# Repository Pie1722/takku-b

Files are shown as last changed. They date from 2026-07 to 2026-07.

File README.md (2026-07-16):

# takku:b

github intro

<p align="justify">
Most DIY binary watches sacrifice battery life for simplicity. I wanted to build one that could run for months from a CR2032 while still remaining compact and stylish. Using an STM32L0 microcontroller and aggressive power optimization, this watch sleeps at under 10 µA and only wakes when needed.
</p>
<p align="justify">
This watch consumes very little amount of power and thus it can run forever on the CR2032 battery but of course due to its self discharge, it will last for around 8-10 years. Along with time it shows weekday, date, month, year and you can even set alarms!
</p>

---

## Features

  1. Time (HH:MM)
  2. Weekday and Date
  3. Month and Year
  4. Set Alarm A and B
  5. Long lasting battery life "**4+ years**"
  6. Field watch style strap "**22mm NATO**"

## Reading Time

reading time

<p align = "justify">
Reading the time in this watch is very easy. Just as the name suggests, it shows time in binary, more specifically it shows in (BCD) Binary Coded Decimal. BCD is a type of encoding in which each number is represented by fixed number of bits. So to show time we need 4 number in which two are for hours and then the other two are for minutes. Each binary digit has its own weight. The bottom digit represents 1 and the top most represents 8. So we need 16 LEDs to show the time (4 rows and 4 columns).
</p>
<p align = "justify">
So to read the time just add the digits in which the LED is turned on and ignore the one's which are off. See the above figure for better understanding.
</p>

---

## How To Use?

wach label

**Note**: See the above figures for the naming conventions.

**General**

  1. Press the button (A) to turn on the display and see the time.
  2. To view Weekday and Date press the button (A) again. First two columns shows the Weekday in which Monday is represented by 1 and Sunday as 7 and the last two columns shows Date.
  3. To view Month and Year press the button (A) again. First two columns shows the Month and last two columns shows the year.
  4. This watch goes on in this cyclic way with each button press. First it shows Time -> Weekday & Date -> Month & Year. Time is represented with a beep to avoid confusion.
  5. The display remains on for 5 seconds. To change the display timeout see the Step 5.

**Setting Mode**

  1. To enter setting mode press the button (A) once to turn on the watch and got to the specific screen then keep pressing button (A) until you hear a beep which indicated you are in setting mode.
  2. To set the time press the button (A) and and enter the time screen and then keep pressing the button (A) until you hear a beep.
  3. Once inside setting mode, press button (B) to increment the numbers.
  4. To change the current field inside the setting mode then press button (C) once. Example - After setting the Hour then press button (C) and set the minutes. If the button (C) is pressed again it will go again to the hour setting mode.
  5. To exit the setting mode, keep pressing the button (A) until you hear a beep.
  6. For setting the other parameter of the watch go to that specific screen and follow the above instruction.

**Setting Alarm**

  1. To view the current alarm, press button (C) after turning the watch on.
  2. To turn on the alarm press the button (B) and same to turn it off. The alarm turned on will be indicated by a red led.
  3. To edit the alarm, press button (A) for one second until you hear the beep, to enter alarm editing mode.
  4. Then use button (B) to increment the value.
  5. To change the field between hour and minute, press button (C).
  6. To exit the alarm edit mode press the button (A) for one second till you hear the beep.
  7. Then either turn on or turn off the alarm by pressing the button (B).
  8. To stop the alarm after it is triggered at the set time, press button (A).
     
  **Note**: The alarm time is stored even if the battery is removed. But it wont be enabled, to turn on the alarm, enter the alarm mode and press the button (B) to turn it on.

**Flow Of Screen**

    Normal Mode -> Screen Time -> Screen Weekday_Date -> Screen Month_Year

---

# Hardware

## PCB Design

The PCB is fully open-sourced and is designed in EasyEDA standard edition. The PCB size is 36mm * 36mm. You can download the gerber files for PCB manufacturing from [/Gerber](Gerber/)

Schematic_Binary-Watch_2026-06-24



3d

## CAD Design

The watch enclosure was designed considering the PCB dimensions. We used a standard 22mm spacing for the watch strap. Designed considered Using a NATO watch strap. The enclosure was designed with tolerance to avoid manufacturing inaccuracies. The design includes a total of 8 holes. 4 holes in front for mounting the glass and four in back to mount the back panel. Inserts are used has it's difficult to print the threads accurately. The back panel is designed big enough so that the battery can be replaced easily. The edges of the enclosure were rounded to avoid sharp edges. And overall design of all components was kept minimalist so it would be better for 3D printing
FDKBVOYMR0Y8SGP-ezgif com-video-to-gif-converter

cad

---

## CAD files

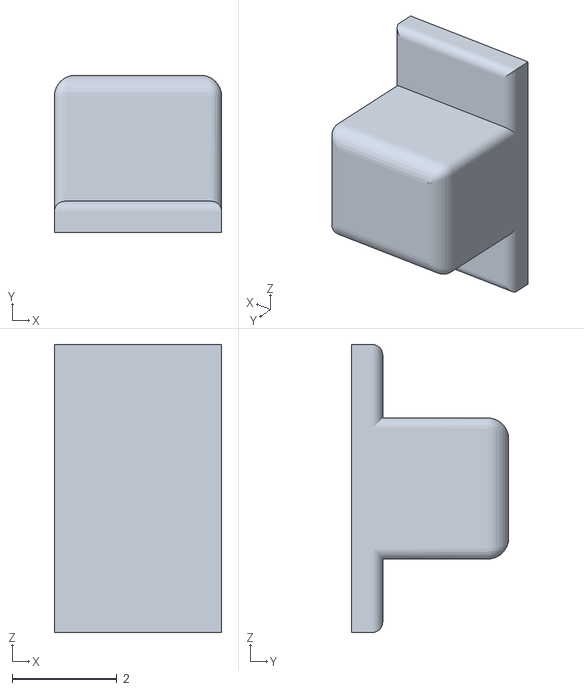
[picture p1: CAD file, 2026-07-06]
3D CAD/Button.stl
3.19 x 3.00 x 5.49

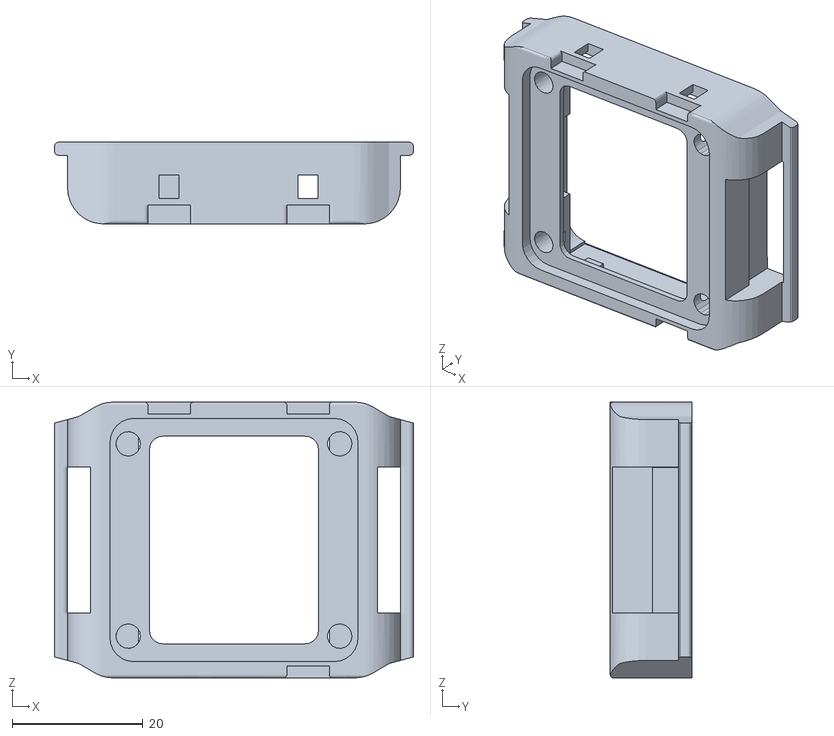
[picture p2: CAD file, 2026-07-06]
3D CAD/Body.stl
55.0 x 12.5 x 42.3

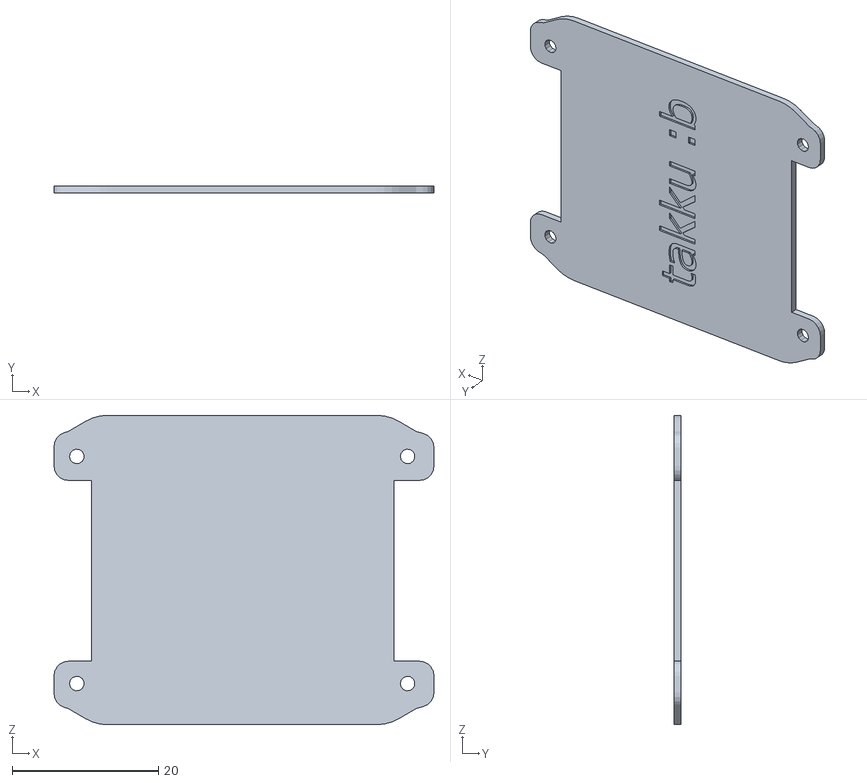
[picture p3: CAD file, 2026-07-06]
3D CAD/Back Panel.stl
51.9 x 1.00 x 42.3

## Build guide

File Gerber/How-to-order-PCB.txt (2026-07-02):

How to Order PCB

Please refer to:
https://docs.easyeda.com/en/PCB/Order-PCB

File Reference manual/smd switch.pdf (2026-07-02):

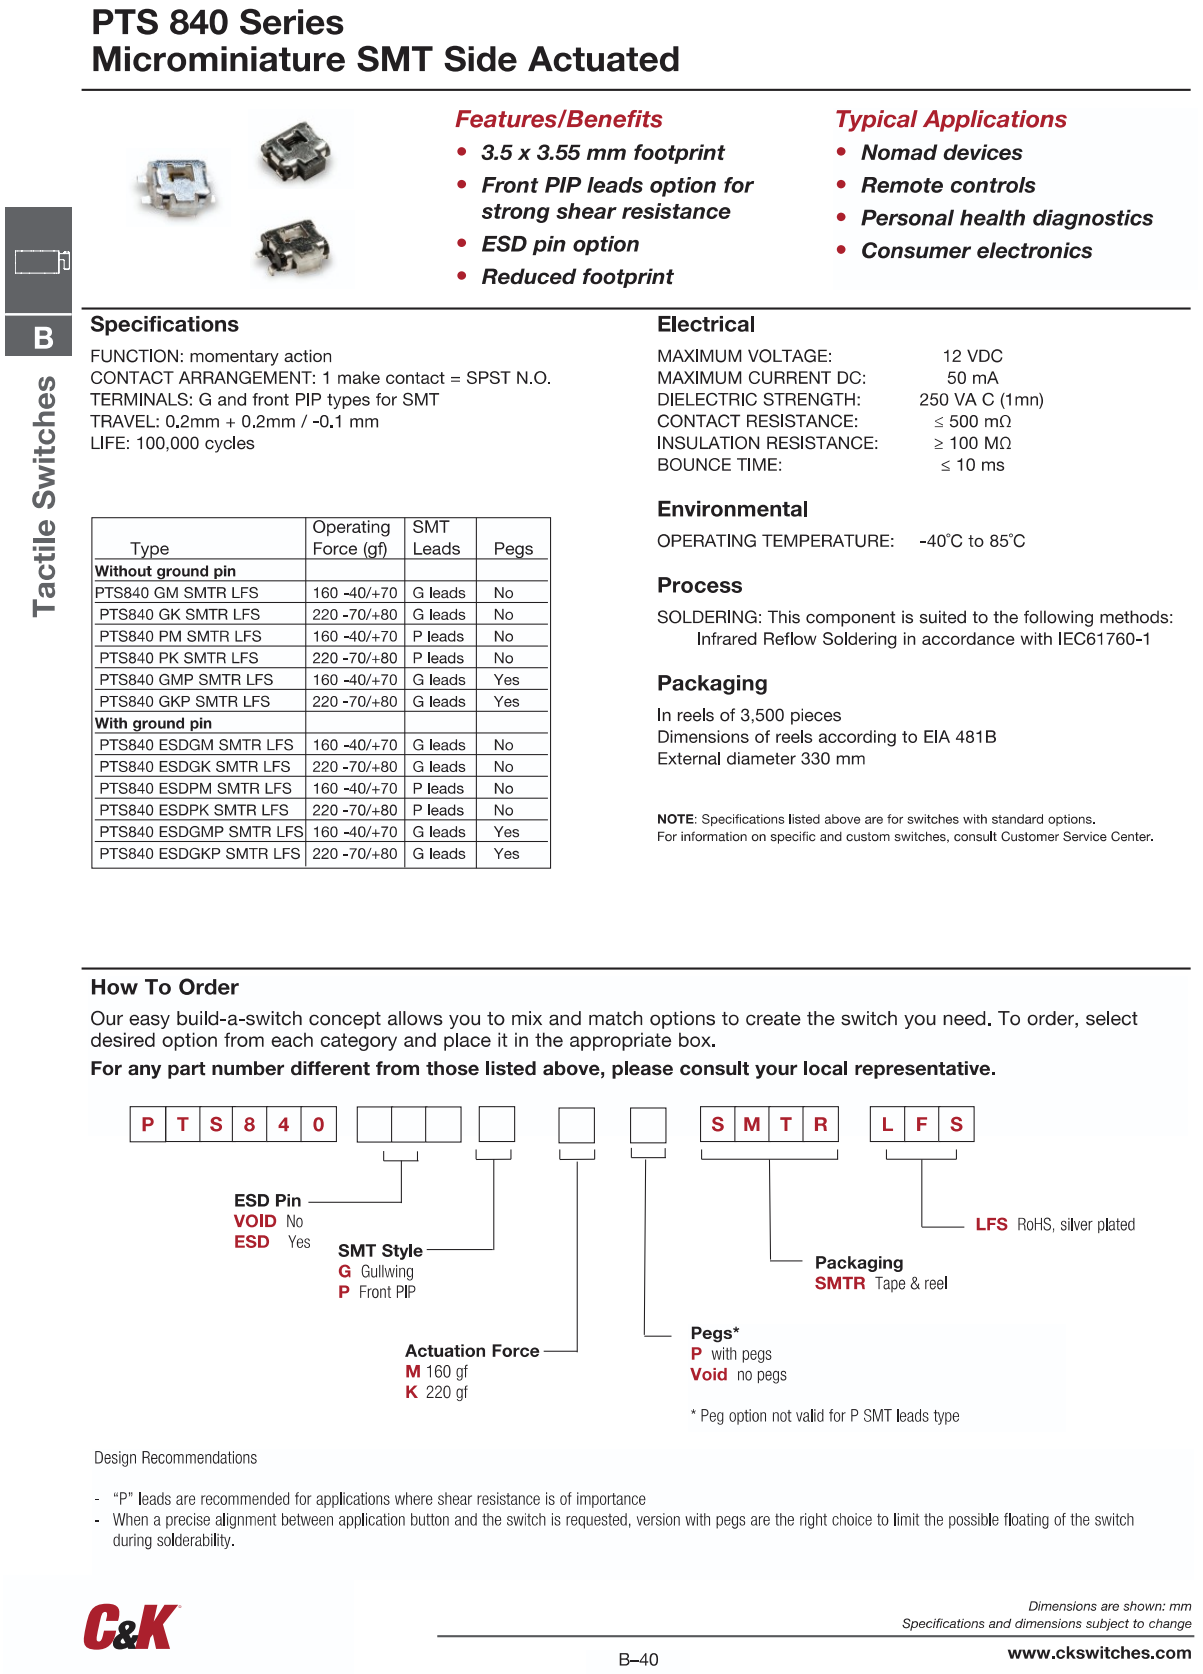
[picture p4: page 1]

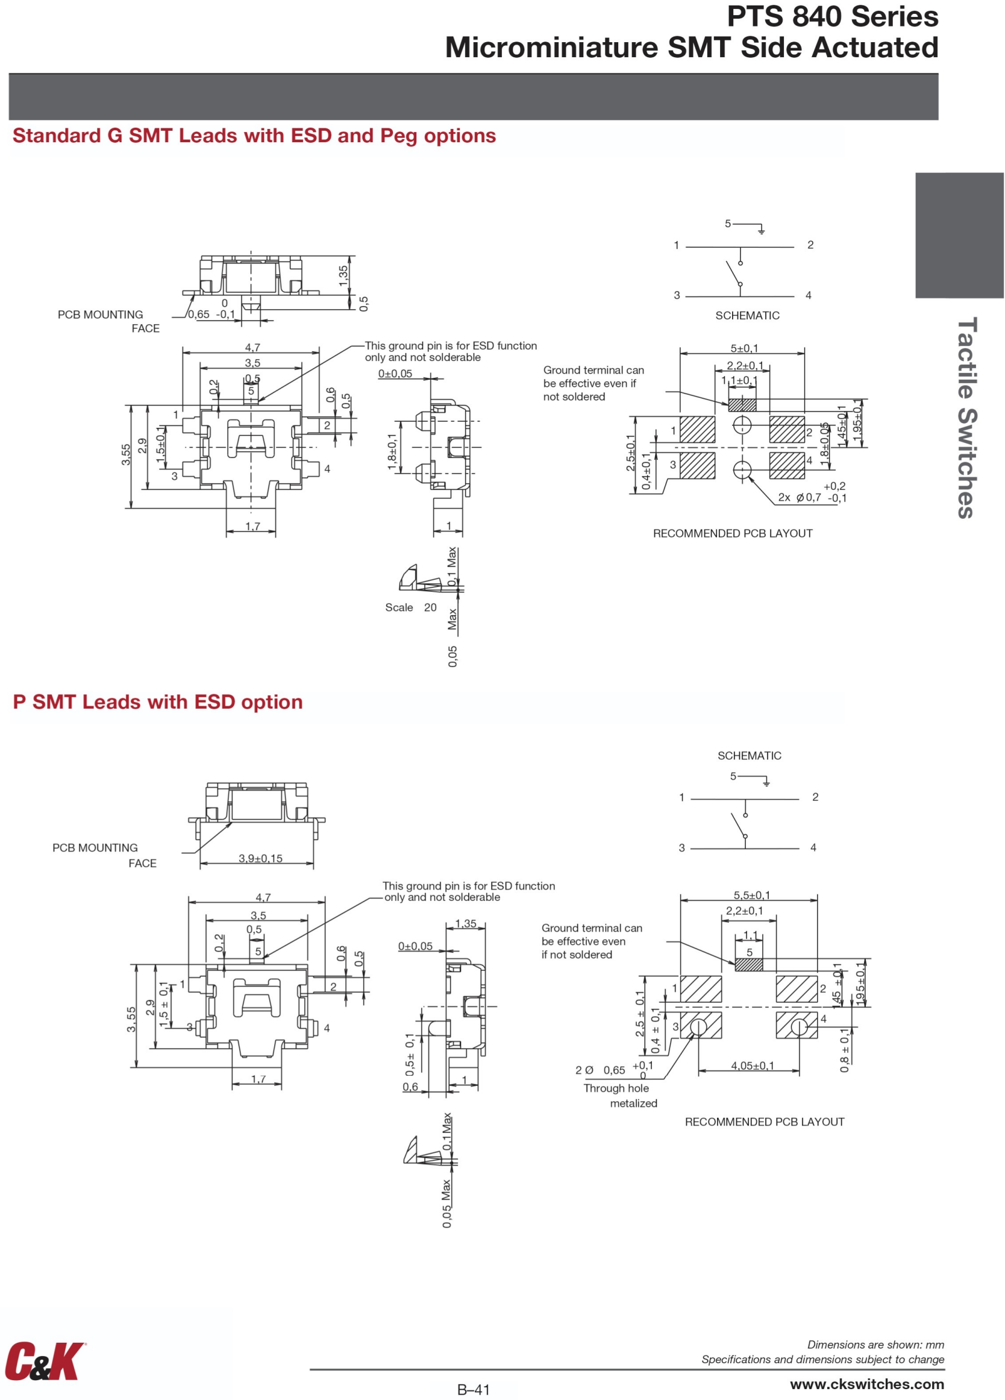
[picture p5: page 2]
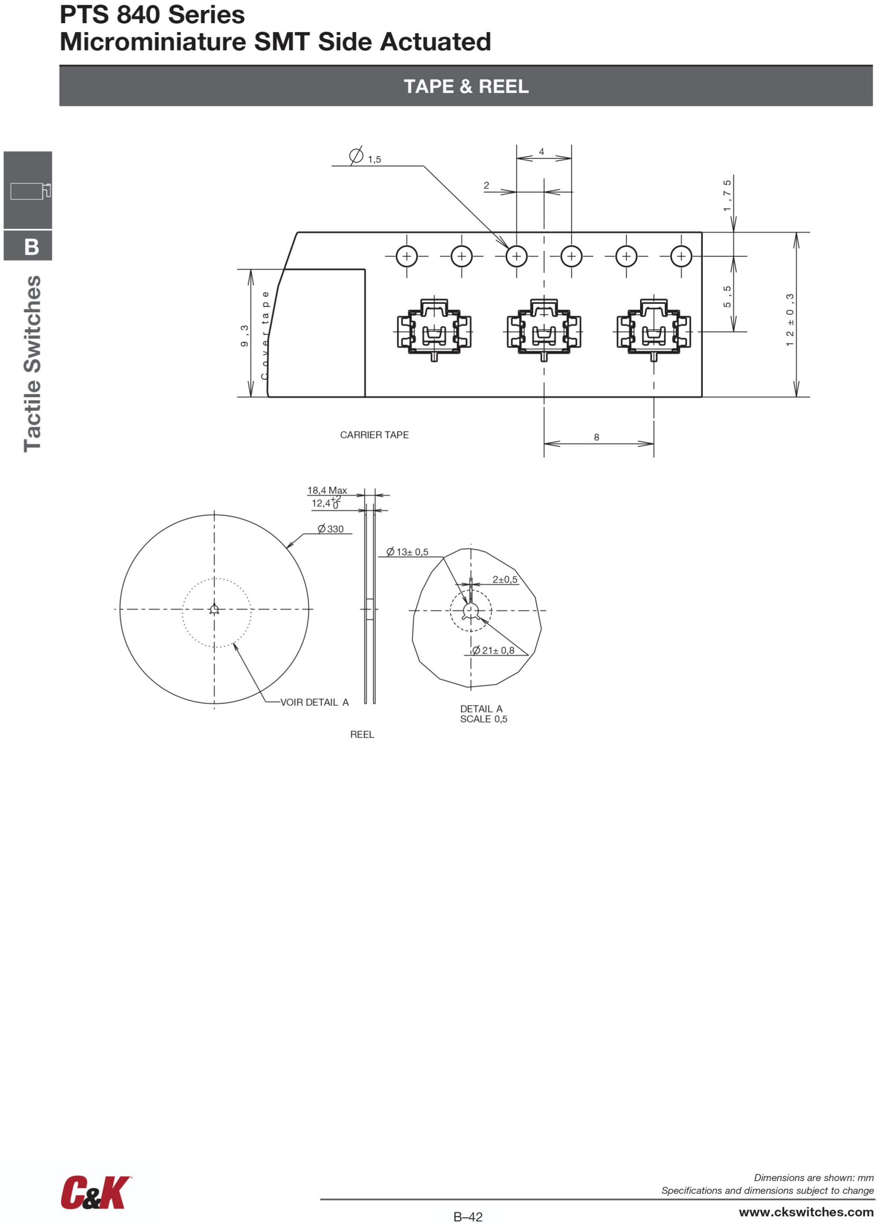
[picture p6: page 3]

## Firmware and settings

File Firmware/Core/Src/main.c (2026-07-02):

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
/* Includes ------------------------------------------------------------------*/
#include "main.h"

/* USER CODE BEGIN PTD */
typedef enum
{
    SCREEN_TIME,
    SCREEN_DATE,
    SCREEN_YEAR,
	SCREEN_ALARM
} DisplayScreen_t;

typedef enum
{
    MODE_NORMAL,
    MODE_SET_HOUR,
    MODE_SET_MINUTE,
    MODE_SET_WEEKDAY,
    MODE_SET_DATE,
    MODE_SET_MONTH,
    MODE_SET_YEAR,
	MODE_SET_ALARM_HOUR,
	MODE_SET_ALARM_MINUTE
} WatchMode_t;
/* USER CODE END PTD */

/* USER CODE BEGIN PD */
uint8_t matrix[4][4]; // 2D array for display

uint8_t hour_tens;
uint8_t hour_ones;
uint8_t min_tens;
uint8_t min_ones;

uint8_t day_tens;
uint8_t day_ones;
uint8_t date_tens;
uint8_t date_ones;

uint8_t year_tens;
uint8_t year_ones;
uint8_t month_tens;
uint8_t month_ones;

uint8_t editHour;
uint8_t editMinute;
uint8_t editWeekday;
uint8_t editDate;
uint8_t editMonth;
uint8_t editYear;

uint8_t alarmHour = 0;
uint8_t alarmMinute = 0;
uint8_t editAlarmHour;
uint8_t editAlarmMinute;
uint8_t alarmEnabled = 0;
uint8_t alarmActive = 0;        // Alarm currently sounding
uint32_t alarmStartTime = 0;    // When the alarm started
uint32_t alarmTimer = 0;        // Timing between beeps
uint8_t beepCount = 0;          // 0..3 beeps in the current burst
uint8_t buzzerOn = 0;           // 0 = OFF, 1 = ON

uint32_t displayTimeout = 0;
uint8_t displayEnabled = 0;

uint32_t buttonPressTime[3] = {0};
uint8_t buttonPressed[3] = {0};
uint32_t lastButtonInterrupt[3] = {0};   // debounce timer

uint8_t settingMode = 0;
/* USER CODE END PD */

RTC_HandleTypeDef hrtc;

TIM_HandleTypeDef htim2;
TIM_HandleTypeDef htim21;

void SystemClock_Config(void);
static void MX_GPIO_Init(void);
static void MX_RTC_Init(void);
static void MX_TIM2_Init(void);
static void MX_TIM21_Init(void);
/* USER CODE BEGIN 0 */

/*
 * Store the pattern in memory matrix
 * The digit and the column where to print is sent.
 * Then the row is selected by the AND operation and check if the output is true or false (1 or 0)
 * 		digit = 6 = 0110
 * 		0110 * 1000 = 0 so the 8th bit row will turn off
 * 		0110 * 0100 = 1 so the 4th bit row will turn on
 * 		0110 * 0010 = 1 so the 2nd bit row will turn on
 * 		0110 * 0001 = 0 so the 1st bit row will turn off
 */
void SetColumnMem(uint8_t col, uint8_t digit)
{
    matrix[0][col] = (digit & 0x08) ? 1 : 0; // 8
    matrix[1][col] = (digit & 0x04) ? 1 : 0; // 4
    matrix[2][col] = (digit & 0x02) ? 1 : 0; // 2
    matrix[3][col] = (digit & 0x01) ? 1 : 0; // 1
}

// Turn off LEDs before the next pattern
void DisableAllColumns(void)
{
    HAL_GPIO_WritePin(GPIOA, COL_1_Pin, GPIO_PIN_SET);
    HAL_GPIO_WritePin(GPIOA, COL_2_Pin, GPIO_PIN_SET);
    HAL_GPIO_WritePin(GPIOA, COL_3_Pin, GPIO_PIN_SET);
    HAL_GPIO_WritePin(GPIOA, COL_4_Pin, GPIO_PIN_SET);
}

//------ Convert the patter stored in memory to GPIO ---------

/*
 * Check each matrix to see which row is to be set or reset.
 * if matrix[0][1] is set then set the row 4 pin
 */
void SetRows(uint8_t col)
{
    HAL_GPIO_WritePin(GPIOB, ROW_1_Pin,
        matrix[0][col] ? GPIO_PIN_SET : GPIO_PIN_RESET);

    HAL_GPIO_WritePin(GPIOB, ROW_2_Pin,
        matrix[1][col] ? GPIO_PIN_SET : GPIO_PIN_RESET);

    HAL_GPIO_WritePin(GPIOB, ROW_3_Pin,
        matrix[2][col] ? GPIO_PIN_SET : GPIO_PIN_RESET);

    HAL_GPIO_WritePin(GPIOB, ROW_4_Pin,
        matrix[3][col] ? GPIO_PIN_SET : GPIO_PIN_RESET);
}

// Reset the column based on the user column entry
void SetColumn(uint8_t col)
{
    switch(col)
    {
        case 0:
            HAL_GPIO_WritePin(GPIOA, COL_1_Pin, GPIO_PIN_RESET);
            break;

        case 1:
            HAL_GPIO_WritePin(GPIOA, COL_2_Pin, GPIO_PIN_RESET);
            break;

        case 2:
            HAL_GPIO_WritePin(GPIOA, COL_3_Pin, GPIO_PIN_RESET);
            break;

        case 3:
            HAL_GPIO_WritePin(GPIOA, COL_4_Pin, GPIO_PIN_RESET);
            break;
    }
}

void getTime(void)
{
	RTC_TimeTypeDef sTime;
	RTC_DateTypeDef sDate;

    /* Get the RTC current Time */
	HAL_RTC_GetTime(&hrtc, &sTime, RTC_FORMAT_BIN);
	/* Get the RTC current Date */
    HAL_RTC_GetDate(&hrtc, &sDate, RTC_FORMAT_BIN);

    hour_tens = sTime.Hours / 10;
    hour_ones = sTime.Hours % 10;
    min_tens  = sTime.Minutes / 10;
    min_ones  = sTime.Minutes % 10;

    // HH : MM
    SetColumnMem(0, hour_tens);
    SetColumnMem(1, hour_ones);
    SetColumnMem(2, min_tens);
    SetColumnMem(3, min_ones);
}

void getDate(void)
{
	RTC_TimeTypeDef sTime;
	RTC_DateTypeDef sDate;

    /* Get the RTC current Time */
	HAL_RTC_GetTime(&hrtc, &sTime, RTC_FORMAT_BIN);
	/* Get the RTC current Date */
    HAL_RTC_GetDate(&hrtc, &sDate, RTC_FORMAT_BIN);

    day_tens = sDate.WeekDay / 10;
    day_ones = sDate.WeekDay % 10;
    date_tens  = sDate.Date / 10;
    date_ones  = sDate.Date % 10;

    // WD : DD
    SetColumnMem(0, day_tens);
    SetColumnMem(1, day_ones);
    SetColumnMem(2, date_tens);
    SetColumnMem(3, date_ones);
}

void getYear(void)
{
	RTC_TimeTypeDef sTime;
	RTC_DateTypeDef sDate;

    /* Get the RTC current Time */
	HAL_RTC_GetTime(&hrtc, &sTime, RTC_FORMAT_BIN);
	/* Get the RTC current Date */
    HAL_RTC_GetDate(&hrtc, &sDate, RTC_FORMAT_BIN);

    month_tens = sDate.Month / 10;
    month_ones = sDate.Month % 10;
    year_tens  = sDate.Year / 10;
    year_ones  = sDate.Year % 10;

    // MM : YY
    SetColumnMem(0, month_tens);
    SetColumnMem(1, month_ones);
    SetColumnMem(2, year_tens);
    SetColumnMem(3, year_ones);
}

/*
 * Initialize the enum with default screen and mode and change the enum to enter the different modes.
 * See the functions below for more info
 */
DisplayScreen_t currentScreen = SCREEN_YEAR;
WatchMode_t currentMode = MODE_NORMAL;

/*
 * Entering to setting mode based on the screens
 * So if the currentScreen is SCREEN_TIME
 * then it should go into MODE_SET_HOUR to change the hour.
*/
void EnterSettingMode(void)
{
    RTC_TimeTypeDef sTime;
    RTC_DateTypeDef sDate;

    HAL_RTC_GetTime(&hrtc, &sTime, RTC_FORMAT_BIN);
    HAL_RTC_GetDate(&hrtc, &sDate, RTC_FORMAT_BIN);

    editHour = sTime.Hours;
    editMinute = sTime.Minutes;

    editWeekday = sDate.WeekDay;
    editDate = sDate.Date;

    editMonth = sDate.Month;
    editYear = sDate.Year;

    switch(currentScreen) // Check the currentScreen typedef and enter the appropriate setting modes
    {
        case SCREEN_TIME:
            currentMode = MODE_SET_HOUR; // Change the Hours
            break;

        case SCREEN_DATE:
            currentMode = MODE_SET_WEEKDAY; // Change the Weekday
            break;

        case SCREEN_YEAR:
            currentMode = MODE_SET_MONTH; // Change the month
            break;

        case SCREEN_ALARM:

            editAlarmHour = alarmHour;
            editAlarmMinute = alarmMinute;
            currentMode = MODE_SET_ALARM_HOUR;
            break;
    }
}

/*
 * Once we are inside setting a particular mode then we need to change the mode
 * to set the other field.
 * So after setting the hour we need to set the minutes.
 */
void NextField(void)
{
    switch(currentMode) // Check the currentMode typedef and go into the next mode to change the num
    {
        case MODE_SET_HOUR: // is current mode is in setting hour
            currentMode = MODE_SET_MINUTE; // then enter setting minute once this function is called
            break;
        case MODE_SET_MINUTE:
            currentMode = MODE_SET_HOUR;
            break;

        case MODE_SET_WEEKDAY:
            currentMode = MODE_SET_DATE;
            break;
        case MODE_SET_DATE:
            currentMode = MODE_SET_WEEKDAY;
            break;

        case MODE_SET_MONTH:
            currentMode = MODE_SET_YEAR;
            break;
        case MODE_SET_YEAR:
            currentMode = MODE_SET_MONTH;
            break;

        case MODE_SET_ALARM_HOUR:
            currentMode = MODE_SET_ALARM_MINUTE;
            break;
        case MODE_SET_ALARM_MINUTE:
            currentMode = MODE_SET_ALARM_HOUR;
            break;

        default:
            currentMode = MODE_NORMAL;
            break;
    }
}

/*
 * This function is to increment the values in each and every mode based on the
 * current mode.
 *
 * SCREEN_TIME:
 * 			MODE_SET_HOUR
 * 			MODE_SET_MINUTE
 * SCREEN_DAY:
 * 			MODE_SET_WEEKDAY
 * 			MODE_SET_DAY
 * SCREEN_YEAR:
 * 			MODE_SET_MONTH
 * 			MODE_SET_YEAR
 *
 * All the changes to the time is done to temp variables.
 */

void IncrementCurrentField(void)
{
    switch(currentMode)
    {
        case MODE_SET_HOUR:

            editHour++;

            if(editHour > 23)
                editHour = 0;

            break;

        case MODE_SET_MINUTE:

            editMinute++;

            if(editMinute > 59)
                editMinute = 0;

            break;

        case MODE_SET_WEEKDAY:

            editWeekday++;

            if(editWeekday > 7)
                editWeekday = 1;

            break;

        case MODE_SET_DATE:

            editDate++;

            if(editDate > 31)
                editDate = 1;

            break;

        case MODE_SET_MONTH:

            editMonth++;

            if(editMonth > 12)
                editMonth = 1;

            break;

        case MODE_SET_YEAR:

            editYear++;

            if(editYear > 99)
                editYear = 0;

            break;

        case MODE_SET_ALARM_HOUR:

            editAlarmHour++;

            if(editAlarmHour > 23)
            {
                editAlarmHour = 0;
            }

            break;

        case MODE_SET_ALARM_MINUTE:

            editAlarmMinute++;

            if(editAlarmMinute > 59)
            {
                editAlarmMinute = 0;
            }

            break;

        default:
            break;
    }
}

void ShowSettingValue(void)
{
    switch(currentScreen)
    {
        case SCREEN_TIME:

            SetColumnMem(0, editHour / 10);
            SetColumnMem(1, editHour % 10);
            SetColumnMem(2, editMinute / 10);
            SetColumnMem(3, editMinute % 10);

            break;

        case SCREEN_DATE:

            SetColumnMem(0, editWeekday / 10);
            SetColumnMem(1, editWeekday % 10);
            SetColumnMem(2, editDate / 10);
            SetColumnMem(3, editDate % 10);

            break;

        case SCREEN_YEAR:

            SetColumnMem(0, editMonth / 10);
            SetColumnMem(1, editMonth % 10);
            SetColumnMem(2, editYear / 10);
            SetColumnMem(3, editYear % 10);

            break;

        case SCREEN_ALARM:

            SetColumnMem(0, editAlarmHour / 10);
            SetColumnMem(1, editAlarmHour % 10);
            SetColumnMem(2, editAlarmMinute / 10);
            SetColumnMem(3, editAlarmMinute % 10);

            break;
    }
}

void beep()
{

    HAL_TIM_PWM_Start(&htim21, TIM_CHANNEL_2);

    HAL_Delay(20);

    HAL_TIM_PWM_Stop(&htim21, TIM_CHANNEL_2);
}

void getAlarm(void)
{
    SetColumnMem(0, alarmHour / 10);
    SetColumnMem(1, alarmHour % 10);
    SetColumnMem(2, alarmMinute / 10);
    SetColumnMem(3, alarmMinute % 10);

    if(alarmEnabled)
    {
        matrix[0][0] = 1;
    }
    else
    {
        matrix[0][0] = 0;
    }
}
/* USER CODE END 0 */

/**
  * @brief  The application entry point.
  * @retval int
  */
int main(void)
{

  /* MCU Configuration--------------------------------------------------------*/

  /* Reset of all peripherals, Initializes the Flash interface and the Systick. */
  HAL_Init();

  /* Configure the system clock */
  SystemClock_Config();

  /* Initialize all configured peripherals */
  MX_GPIO_Init();
  MX_RTC_Init();
  MX_TIM2_Init();
  MX_TIM21_Init();
  /* USER CODE BEGIN 2 */
  HAL_TIM_Base_Start_IT(&htim2);
  __HAL_TIM_SET_COMPARE(&htim21, TIM_CHANNEL_2, 50);

  // read the alarm  from eeprom
  alarmHour = *(uint8_t *)0x08080000;
  alarmMinute = *(uint8_t *)0x08080001;
//beep();
//  __HAL_TIM_SET_COMPARE(&htim21, TIM_CHANNEL_2, 250);
//  HAL_TIM_PWM_Start(&htim21, TIM_CHANNEL_2);
  /* USER CODE END 2 */

  /* Infinite loop */
  /* USER CODE BEGIN WHILE */
  while (1)
  {
	  if(alarmActive && buttonPressed[0])
	  {
	      alarmActive = 0;
	      HAL_TIM_PWM_Stop(&htim21, TIM_CHANNEL_2);
	      buttonPressed[0] = 0;
	  }

	  if(alarmActive)
	  {
	      uint32_t now = HAL_GetTick();

	      // Stop after 20 seconds
	      if((now - alarmStartTime) >= 20000)
	      {
	          alarmActive = 0;
	          HAL_TIM_PWM_Stop(&htim21, TIM_CHANNEL_2);
	      }
	      else
	      {
	          if(buzzerOn)
	          {
	              // ON for 80ms
	              if((now - alarmTimer) >= 80)
	              {
	                  HAL_TIM_PWM_Stop(&htim21, TIM_CHANNEL_2);

	                  buzzerOn = 0;
	                  alarmTimer = now;

	                  beepCount++;
	              }
	          }
	          else
	          {
	              if(beepCount < 4)
	              {
	                  // OFF between beeps (80ms)
	                  if((now - alarmTimer) >= 80)
	                  {
	                      HAL_TIM_PWM_Start(&htim21, TIM_CHANNEL_2);

	                      buzzerOn = 1;
	                      alarmTimer = now;
	                  }
	              }
	              else
	              {
	                  // Pause after 4 beeps (250ms)
	                  if((now - alarmTimer) >= 500)
	                  {
	                      beepCount = 0;

	                      HAL_TIM_PWM_Start(&htim21, TIM_CHANNEL_2);

	                      buzzerOn = 1;
	                      alarmTimer = now;
	                  }
	              }
	          }
	      }
	  }

	  if(currentMode == MODE_NORMAL)
	  {
	      if(HAL_GPIO_ReadPin(GPIOB, GPIO_PIN_2) == GPIO_PIN_RESET)
	      {
	          uint32_t now = HAL_GetTick();

	          if(buttonPressed[2] == 0 &&
	             (now - lastButtonInterrupt[2]) > 100)
	          {
	              if(currentScreen != SCREEN_ALARM)
	              {
	                  currentScreen = SCREEN_ALARM;
	                  getAlarm();
	              }
	              else
	              {
	                  currentScreen = SCREEN_TIME;
	                  getTime();
	              }

	              displayEnabled = 1;
	              displayTimeout = HAL_GetTick();

	              beep();

	              buttonPressed[2] = 1;
	              lastButtonInterrupt[2] = now;
	          }
	      }
	      else
	      {
	          buttonPressed[2] = 0;
	      }
	  }

	  if(currentMode == MODE_NORMAL && currentScreen == SCREEN_ALARM)
	  {
	      if(HAL_GPIO_ReadPin(GPIOB, GPIO_PIN_1) == GPIO_PIN_RESET)
	      {
	          uint32_t now = HAL_GetTick();

	          if(buttonPressed[1] == 0 &&
	              (now - lastButtonInterrupt[1]) > 100)
	          {
	              alarmEnabled = !alarmEnabled;

	              if(alarmEnabled)
	              {
	                  RTC_AlarmTypeDef sAlarm = {0};

	                  sAlarm.AlarmTime.Hours = alarmHour;
	                  sAlarm.AlarmTime.Minutes = alarmMinute;
	                  sAlarm.AlarmTime.Seconds = 0;
	                  sAlarm.AlarmTime.SubSeconds = 0;
	                  sAlarm.AlarmTime.DayLightSaving = RTC_DAYLIGHTSAVING_NONE;
	                  sAlarm.AlarmTime.StoreOperation = RTC_STOREOPERATION_RESET;
	                  sAlarm.AlarmMask = RTC_ALARMMASK_DATEWEEKDAY;
	                  sAlarm.AlarmSubSecondMask = RTC_ALARMSUBSECONDMASK_ALL;
	                  sAlarm.AlarmDateWeekDaySel = RTC_ALARMDATEWEEKDAYSEL_DATE;
	                  sAlarm.AlarmDateWeekDay = 1;
	                  sAlarm.Alarm = RTC_ALARM_A;

	                  HAL_RTC_SetAlarm_IT(&hrtc, &sAlarm, RTC_FORMAT_BIN);

	                  matrix[0][0] = 1;
	              }
	              else
	              {
	                  HAL_RTC_DeactivateAlarm(&hrtc, RTC_ALARM_A);
	                  matrix[0][0] = 0;
	              }

	              beep();

	              buttonPressed[1] = 1;
	              lastButtonInterrupt[1] = now;
	          }
	      }
	      else
	      {
	          buttonPressed[1] = 0;
	      }
	  }

	  if(currentMode != MODE_NORMAL)
	  {
	      displayEnabled = 1;
	      ShowSettingValue();

	      if(HAL_GPIO_ReadPin(GPIOB, GPIO_PIN_1) == GPIO_PIN_RESET)
	      {
	          uint32_t now = HAL_GetTick();

	          if(buttonPressed[1] == 0 &&
	             (now - lastButtonInterrupt[1]) > 100)
	          {
	              IncrementCurrentField();

	              buttonPressed[1] = 1;
	              lastButtonInterrupt[1] = now;
	          }
	      }
	      else
	      {
	          buttonPressed[1] = 0;
	      }


	      if(HAL_GPIO_ReadPin(GPIOB, GPIO_PIN_2) == GPIO_PIN_RESET)
	      {
	          uint32_t now = HAL_GetTick();

	          if(buttonPressed[2] == 0 &&
	             (now - lastButtonInterrupt[2]) > 50)
	          {
	              NextField();
	              beep();

	              buttonPressed[2] = 1;
	              lastButtonInterrupt[2] = now;
	          }
	      }
	      else
	      {
	          buttonPressed[2] = 0;
	      }


	      if(buttonPressed[0])
	      {
	          if(HAL_GPIO_ReadPin(GPIOB, GPIO_PIN_0) == GPIO_PIN_RESET)
	          {
	              if((HAL_GetTick() - buttonPressTime[0]) >= 1000)
	              {
	            	  RTC_TimeTypeDef sTime;
	            	  RTC_DateTypeDef sDate;

	            	  HAL_RTC_GetTime(&hrtc, &sTime, RTC_FORMAT_BIN);
	            	  HAL_RTC_GetDate(&hrtc, &sDate, RTC_FORMAT_BIN);

	            	  sTime.Hours = editHour;
	            	  sTime.Minutes = editMinute;

	            	  sDate.WeekDay = editWeekday;
	            	  sDate.Date = editDate;
	            	  sDate.Month = editMonth;
	            	  sDate.Year = editYear;

	            	  HAL_RTC_SetTime(&hrtc, &sTime, RTC_FORMAT_BIN);
	            	  HAL_RTC_SetDate(&hrtc, &sDate, RTC_FORMAT_BIN);

	            	  if(currentScreen == SCREEN_ALARM)
	            	  {
	            	      alarmHour = editAlarmHour;
	            	      alarmMinute = editAlarmMinute;

	            	      // save into eeprom so the memory retains even after powerloss
	            	      HAL_FLASHEx_DATAEEPROM_Unlock();

	            	      HAL_FLASHEx_DATAEEPROM_Program(FLASH_TYPEPROGRAMDATA_BYTE,
	            	                                     0x08080000,
	            	                                     alarmHour);

	            	      HAL_FLASHEx_DATAEEPROM_Program(FLASH_TYPEPROGRAMDATA_BYTE,
	            	                                     0x08080001,
	            	                                     alarmMinute);

	            	      HAL_FLASHEx_DATAEEPROM_Lock();
	            	  }

            	      currentMode = MODE_NORMAL;
            	      settingMode = 0;

            	      buttonPressed[0] = 0;
            	      buttonPressTime[0] = 0;

            	      displayEnabled = 1;
            	      displayTimeout = HAL_GetTick();

            	      beep();
	              }
	          }
	      }
	      continue;
	  }

	  if(buttonPressed[0])
	  {
	      if(HAL_GPIO_ReadPin(GPIOB, GPIO_PIN_0) == GPIO_PIN_RESET)
	      {
	    	  if(displayEnabled){
		          if((HAL_GetTick() - buttonPressTime[0]) >= 1000)
		          {
		              buttonPressed[0] = 0;   // prevent repeated entry
		              settingMode = 1;
		              beep();
		              EnterSettingMode();
		          }
	    	  }
	      }
	      else
	      {

	    	  displayEnabled = 1;
	          displayTimeout = HAL_GetTick();

	          switch(currentScreen)
	          {
	          	  case SCREEN_TIME:
	          		  currentScreen = SCREEN_DATE;
	                  getDate();
	                  //beep();
	                  break;

	              case SCREEN_DATE:
	                  currentScreen = SCREEN_YEAR;
	                  getYear();
	                  //beep();
	                  break;

	              case SCREEN_YEAR:
	                  currentScreen = SCREEN_TIME;
	                  getTime();
	                  beep();
	                  break;

	              case SCREEN_ALARM:
	                  // Do nothing.
	                  // PB0 press has no function on the alarm screen.
	                  break;
	          }
	          buttonPressed[0] = 0;
	      }
	  }

	  // Sleep timeout only in normal mode, in setting mode disable timeout

	  if(currentMode == MODE_NORMAL)
	  {
		  if(displayEnabled)
		  {
			  if((HAL_GetTick() - displayTimeout) >= 5000)
			  {
				  displayEnabled = 0;
				  DisableAllColumns();
				  currentScreen = SCREEN_YEAR; // SHOW SCREEN_TIME AFTER WAKEUP. SEE EXTI_CALLBACK() FOR MORE INFO

				  HAL_SuspendTick();

				  HAL_TIM_Base_Stop_IT(&htim2);
				  HAL_TIM_PWM_Stop(&htim21, TIM_CHANNEL_2);

				  __HAL_RCC_TIM2_CLK_DISABLE();
				  __HAL_RCC_TIM21_CLK_DISABLE();

				  HAL_PWREx_EnableUltraLowPower();
				  HAL_PWREx_EnableFastWakeUp();

				  HAL_PWR_EnterSTOPMode(PWR_LOWPOWERREGULATOR_ON,PWR_STOPENTRY_WFI);

				  // RESUME CPU

				  SystemClock_Config();

				  HAL_ResumeTick();

				  __HAL_RCC_TIM2_CLK_ENABLE();
				  __HAL_RCC_TIM21_CLK_ENABLE();

				  HAL_TIM_Base_Start_IT(&htim2);
			  }
		  }
	  }
    /* USER CODE END WHILE */

    /* USER CODE BEGIN 3 */
  }
  /* USER CODE END 3 */
}

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
/* USER CODE BEGIN 4 */
volatile uint8_t currentColumn = 0;

void HAL_TIM_PeriodElapsedCallback(TIM_HandleTypeDef *htim)
{
    if(htim->Instance == TIM2)
    {
        if(!displayEnabled)
        {
            DisableAllColumns();
            return;
        }

        DisableAllColumns();

        SetRows(currentColumn);

        SetColumn(currentColumn);

        currentColumn++;

        if(currentColumn >= 4)
        {
            currentColumn = 0;
        }
    }
}

void HAL_GPIO_EXTI_Callback(uint16_t GPIO_Pin)
{
    if(GPIO_Pin == GPIO_PIN_0)
    {
        uint32_t now = HAL_GetTick();

        // 100ms debounce
        if((now - lastButtonInterrupt[0]) < 100)
            return;

        lastButtonInterrupt[0] = now;

        buttonPressTime[0] = now;
        buttonPressed[0] = 1;
    }
}
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

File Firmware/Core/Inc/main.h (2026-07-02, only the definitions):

#define BUZZER_Pin GPIO_PIN_3
#define BUZZER_GPIO_Port GPIOA
#define ROW_1_Pin GPIO_PIN_12
#define ROW_1_GPIO_Port GPIOB
#define ROW_2_Pin GPIO_PIN_13
#define ROW_2_GPIO_Port GPIOB
#define ROW_3_Pin GPIO_PIN_14
#define ROW_3_GPIO_Port GPIOB
#define ROW_4_Pin GPIO_PIN_15
#define ROW_4_GPIO_Port GPIOB
#define COL_1_Pin GPIO_PIN_8
#define COL_1_GPIO_Port GPIOA
#define COL_2_Pin GPIO_PIN_9
#define COL_2_GPIO_Port GPIOA
#define COL_3_Pin GPIO_PIN_10
#define COL_3_GPIO_Port GPIOA
#define COL_4_Pin GPIO_PIN_11
#define COL_4_GPIO_Port GPIOA

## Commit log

2026-05-24 Add initial HTML structure for STM32L0 Binary Watch
2026-07-06 Updated CAD
    [Back Panel.stl, Body.stl, Button.stl]
2026-07-16 Update README with images of the binary watch
    Added images of the binary watch and PCB to README.
2026-07-16 Clarify gerber file availability in README
    Updated the README to specify that gerber files are for PCB manufacturing.

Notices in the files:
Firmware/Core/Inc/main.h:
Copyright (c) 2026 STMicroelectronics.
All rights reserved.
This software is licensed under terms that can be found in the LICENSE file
